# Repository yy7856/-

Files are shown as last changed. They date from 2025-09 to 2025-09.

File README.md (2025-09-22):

[English](README.en.md) | **简体中文**
✨ 项目概述

本项目是一个完全开源的机械手表设计。它包含了所有必要的CAD设计文件（如STEP, STL）、零件清单（BOM）、以及详细的组装说明。我们的目标是让制表爱好者、工程师和学生们能够以较低的成本体验机械制表的魅力，并鼓励大家在此基础上进行学习、修改和创新。

设计理念： 这是一款自动机械表，简约的外形搭配复杂的机械机芯，是包豪斯和柯布西耶的对撞
目标受众：

机械手表爱好者

3D打印和DIY爱好者

工业设计专业的学生和教育者

开源硬件社区

实物照片
微信图片_20250922094023_86_220
微信图片_20250922094018_85_220

https://github.com/user-attachments/assets/0842e47e-befd-4b44-93c4-97af5a41a2af

https://github.com/user-attachments/assets/bd1f7405-8c59-4fc4-a2c7-ee7b409de569

⚙️ 特性

3D打印主体：表壳、表冠、可使用树脂或金属3D打印制作，大幅降低成本和门槛。

通用机芯：基于广泛可用的通用机械手表机芯（杭州机芯）进行设计，方便采购。

模块化设计： 【如果适用】表耳、表盘、指针等部件可以轻松更换和定制。

📦 所需材料与工具
材料清单 (BOM)
详见 Docs/BOM.xlsx 文件。核心部件包括：

机芯： 杭州1c02d x 1

表针： 一套适合1c02d机芯的表针（通用eta2824机芯表针）

表镜： 蓝宝石或矿物玻璃表镜 (23.2*30.2*1.5 mm)

表带： 通用22mm宽度皮革/金属表带 x 1

3D打印材料： 高精度树脂（用于齿轮）/ 尼龙或金属（用于表壳）

紧固件： M1.6 x 3mm 螺丝 x 8

其他： uv胶，螺丝紧固胶

必要工具

精密螺丝刀套装

水口钳

镊子

针

平口胶水注射器

🛠️ 组装指南
完整的图文/视频组装指南请参阅 Docs/Assembly_Guide.pdf。以下是简要步骤：

准备零件： 打印所有3D部件，去支撑并打磨。清洁所有采购的零件。

安装表镜： 把刻度贴纸贴在表镜上，把表镜放入表壳，注意刻度朝里面，用注射器在表镜周围均匀涂抹uv胶，并用紫外线灯固化。下盖表镜如法炮制。

组装表盘： 夜光版本表盘，需要在刻度槽上涂抹上夜光涂料，干透后放入表壳。

组装防水把管： 将拔管涂抹上螺丝紧固胶，插入表壳拔管位置，静止24小时。

安装指针： 使用指针安装器依次安装时、分、秒针。（注意：这是最需要耐心的步骤！）

装入表壳： 卸下机芯巴杆， 将组装好的“机芯-指针”总成小心地放入表壳。

巴蒂安装； 插入巴蒂把杆

固定表下盖： 盖上下盖，并用螺丝刀拧紧。

安装表带： 将表带弹簧杆穿过表耳。

调试与上链： 为手表上链，检查走时是否正常，调试指针间是否相互摩擦或与表镜摩擦。

🎨 定制与修改
本项目的魅力在于你可以自由地修改它！

表壳设计： 使用 creo/rhino/ 软件来修改表壳的形状、尺寸和纹路。

表盘设计： 我们提供了Adobe Illustrator模板 (表盘.ai) 供你设计属于自己的表盘。

混合材料： 尝试用不同的材料打印零件，比如用不锈钢打印表壳，用透明树脂打印一个“骷髅”表盘。

🙏 致谢
感谢 【杭州机芯李小姐】 的帮助。

感谢 杭州手表有限公司 生产了如此优秀且易于获取的机芯。

感谢所有为本项目提交Issue和PR的贡献者们。

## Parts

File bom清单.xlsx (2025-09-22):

序号 | 名称 | 规格 | 数量 | 单价 | 运费 | 总价 | 链接 | 备注
1 | 上壳 | 6061铝合金 | 1 | 160 | 10 | 170 | 嘉立创cnc
2 | 后盖 | 6061铝合金 | 1 | 6 | 6 | 12
3 | 玻璃 | 钢化玻璃 | 2 | 12 | 10 | 34 | https://item.taobao.com/item.htm?id=600865281027
4 | 机芯 | 1C02D | 1 | 270 | 10 | 280 | https://item.taobao.com/item.htm?id=734661195533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 | 从我这购买比某宝优惠20.
5 | 巴蒂 | 2.4细管 | 1 | 5 | 10 | 15 | https://item.taobao.com/item.htm?from=cart&id=607888731439&skuId=5027224499570&upStreamPrice=588
6 | 支架 | 树脂 | 1 | 10 | 5 | 15 | 3d打印
8 | 表盘 | 树脂 | 1 | 10 | 5 | 15 | 3d打印
9 | 针 | 最长不能超过10mm | 1 | 10 | 10 | 20 | https://item.taobao.com/item.htm?_u=mpana4bd5ec&id=684373627995&skuId=4886868800449
10 | 螺丝 | M1.6*3 | 8 | 1.3 | 0 | 10.4 | https://detail.tmall.com/item.htm?id=778556731894&_u=mpana4b7e19
11 | 刻度贴纸 | 水晶贴 | 1 | 1 | 0 | 1 | https://detail.tmall.com/item.htm?_u=mpana4b764b&id=734990627350
12 | 表带 | 表带尺寸：适用【华为GT4/GT5 46mm/GT5 PRO 46mm】送钢化膜颜色分类：保时捷同款【银色】 | 1 | 70 | 0 | 70 | https://detail.tmall.com/item.htm?_u=mpana4b6364&id=654311091274
13 |  |  |  |  | 66
 |  |  |  |  | 合计: | 642.4
 | 欢迎关注哔哩哔哩：羊嘭嘭嘭，有问题联系QQ:785628119
 | 工具
 | 螺丝刀
 | uv胶
 | 螺丝紧固胶 | =DISPIMG("ID_0F5A83A0F795448BB8100693FB521186",1) |  |  |  |  | https://detail.tmall.com/item.htm?abbucket=20&id=770499545577&ns=1&xxc=taobaoSearch&skuId=5453284719878
 | 水口钳
 | 平口点胶注射器

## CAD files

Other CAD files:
3d step/攻牙位置尺寸.dwg

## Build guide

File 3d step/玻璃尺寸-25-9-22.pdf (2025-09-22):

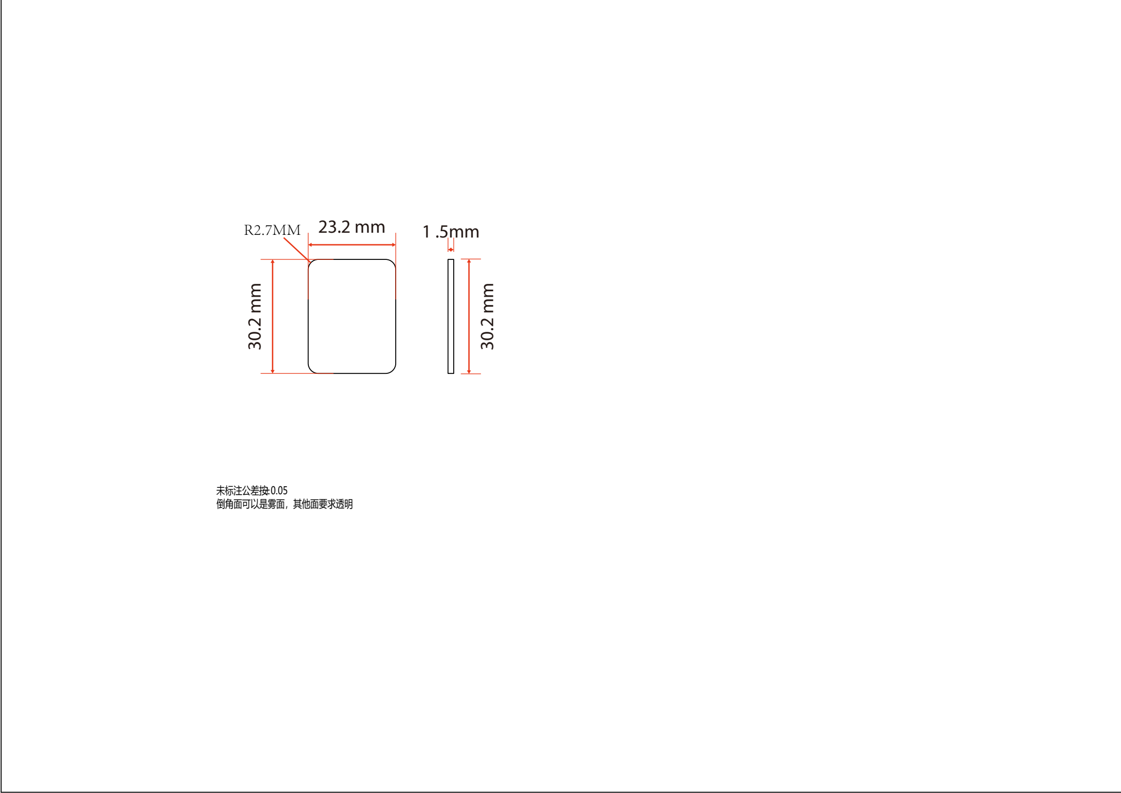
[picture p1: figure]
未标注公差按±0.05 倒角面可以是雾面，其他面要求透明

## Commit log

2025-09-22 Add files via upload
    3d文件
2025-09-22 Add files via upload
    实物
